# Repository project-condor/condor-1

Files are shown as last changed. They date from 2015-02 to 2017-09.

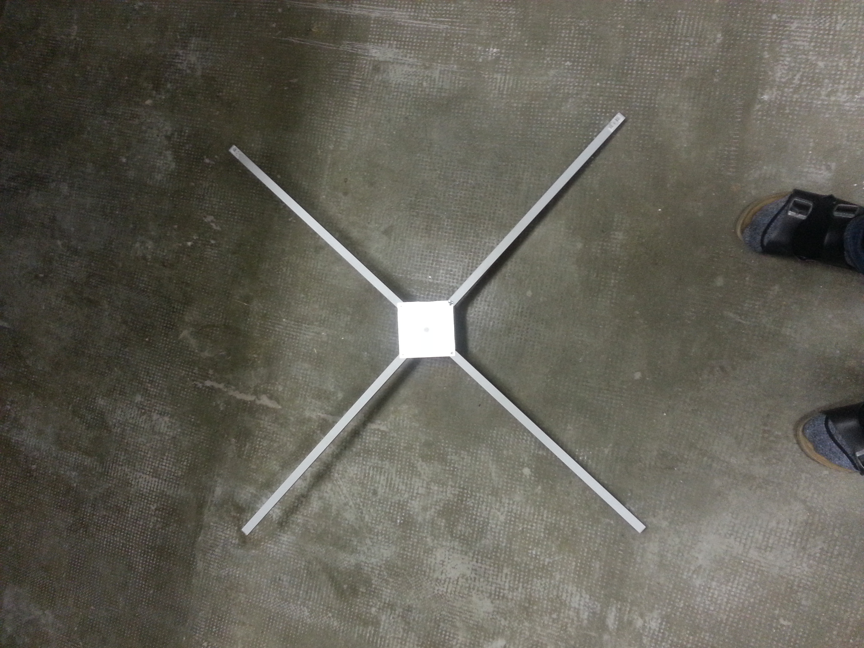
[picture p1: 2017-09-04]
prototype/pictures/frame-final.jpg

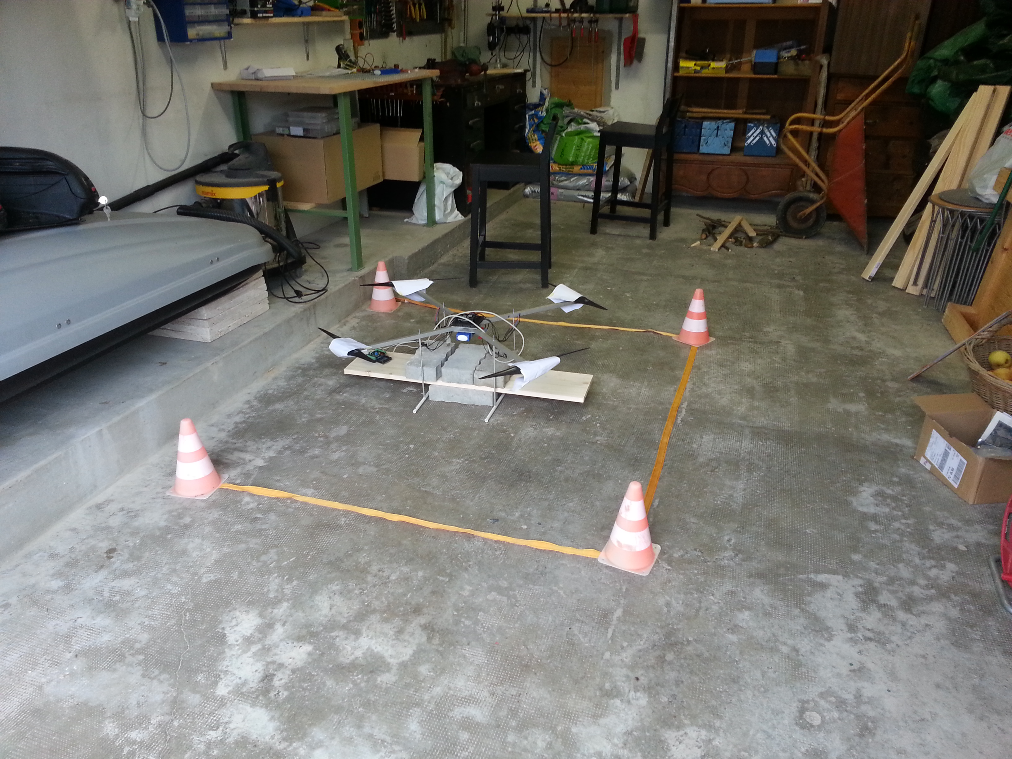
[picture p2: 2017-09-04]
prototype/pictures/condor1.jpg

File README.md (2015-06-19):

# Condor - 1

Project Condor regroups several smaller projects with the aim of creating a fully open source quadcopter.

This repository contains files related to the quadcopter model. Checkout the [functional diagram](functional.svg), and a [computer rendition](prototype/preview.png) of the prototype.

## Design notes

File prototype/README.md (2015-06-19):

# Condor - 1 - 1

This directory contains files related to the first prototype (the actual physical unit) of the condor project.

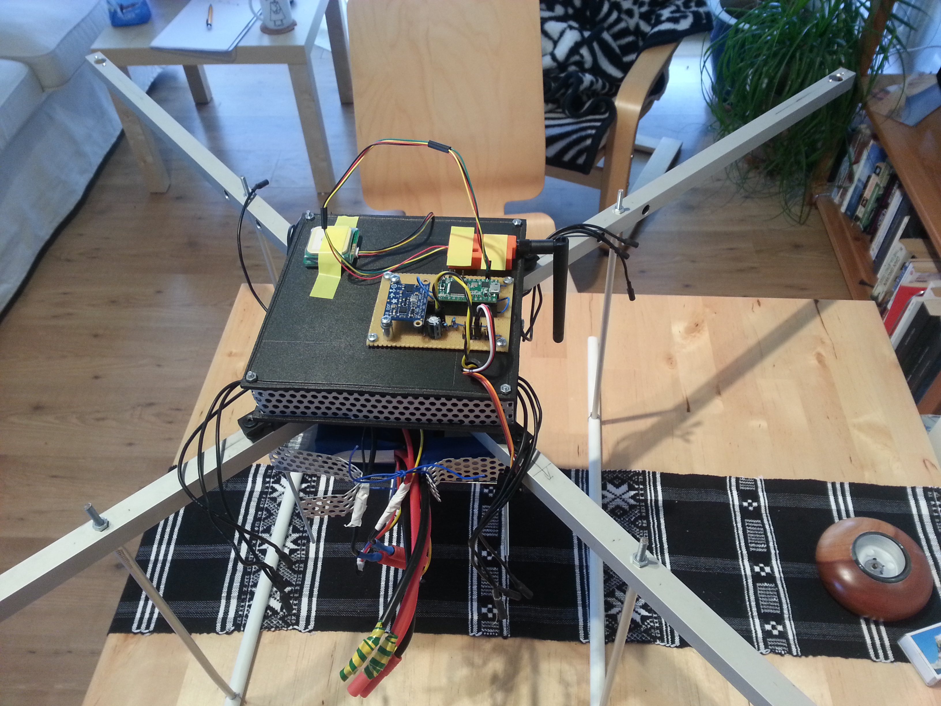
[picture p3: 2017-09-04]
prototype/pictures/closeup.jpg

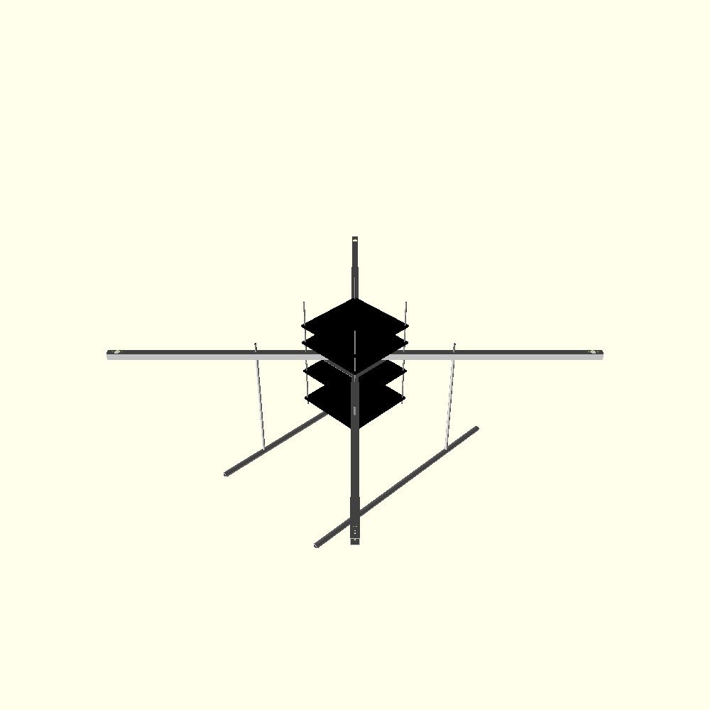
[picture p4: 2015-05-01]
prototype/preview.png

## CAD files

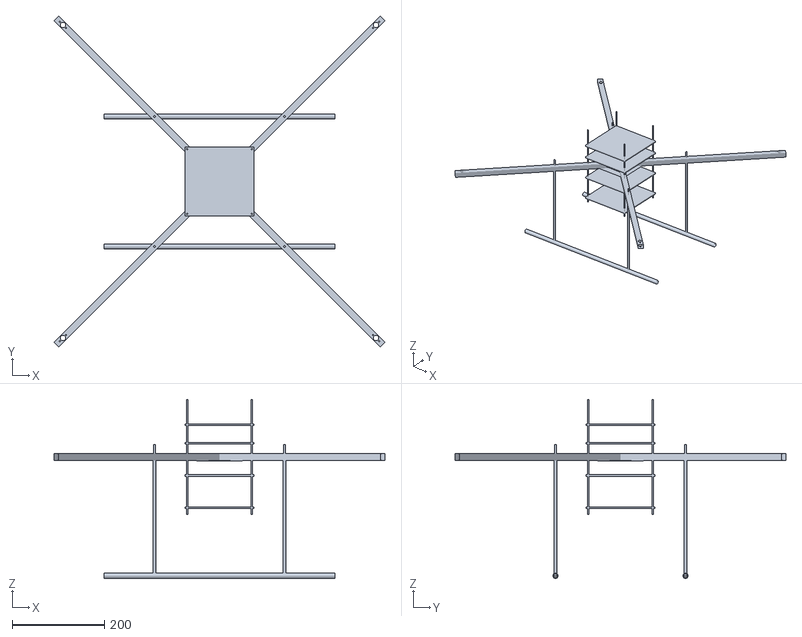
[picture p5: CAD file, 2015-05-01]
prototype/mainframe.stl
717.7 x 717.7 x 388.5

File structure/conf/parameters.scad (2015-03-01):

//rendering
epsilon=0.01;

//model
frame_length=1000;
frame_inner=19;
frame_outer=20;

support_width=100;
support_height=0.2;
support_inner=90;
support_diameter=3;

rack_width=150;
rack_inner=140;
rack_diameter=3;

stand_height=200;
stand_width=200;
stand_diameter=5;
stand_head_height=20;
stand_head_diameter=4;

foot_outer=12;
foot_inner=10;
foot_length=500;

motor_hole_distance=450;
motor_hole_diameter=12;
motor_mount_distance=19;
motor_mount_diameter=3;

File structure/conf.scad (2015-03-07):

//rendering
epsilon=0.1;

//model
frame_length=1000;
frame_inner=13.5;
frame_outer=15;

support_width=100;
support_height=0.75;
support_inner=90;
support_diameter=3;

rack_width=150;
rack_inner=140;
rack_diameter=3;
rack_height=250;
rack_plate_height=4;

stand_height=250;
stand_width=282;
stand_diameter=6;
stand_head_height=35;
stand_head_diameter=4;

foot_outer=12;
foot_inner=8;
foot_length=500;

motor_hole_distance=480;
motor_hole_diameter=12;
motor_mount_distance=19;
motor_mount_diameter=3;

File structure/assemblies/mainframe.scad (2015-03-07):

include <../conf.scad>
use <../parts/crossbar.scad>
use <../parts/support_plate.scad>
use <../parts/stand.scad>
use <../parts/foot.scad>
use <../parts/rack_mount.scad>
use <../parts/rack_plate.scad>

$fn=10;

explode=0;

module main(explode=0) {
	translate([0,0,-explode])
	rotate([0,0,45])
	crossbar();

	translate([0,0,explode])
	rotate([180,0,-45])
	crossbar();
}

module support(explode=0) {
	translate([0,0,explode])
	translate([0,0,(frame_outer+support_height)/2])
	support_plate();

	translate([0,0,-explode])
	translate([0,0,-(frame_outer+support_height)/2])
	support_plate();
}

module stands(explode=0) {
	translate([0,0,-explode])
	for (i = [0:3]) {
		rotate([0,0,i*90])
		translate([stand_width/2,stand_width/2,-stand_height/2 - frame_outer/2])
		stand();
	}
}

module feet(explode=0) {
	translate([0,0,-explode]) {
		translate([0, stand_width/2, -stand_height - frame_outer/2])
		foot();
		translate([0, -stand_width/2, -stand_height - frame_outer/2])
		foot();
	}
}
module rack_mounts(explode=0) {
	translate([0,0,explode])
	for (i = [0:3]) {
		rotate([0,0,i*90])
		translate([rack_inner/2,rack_inner/2,0])
		rack_mount();
	}

}

main(explode);
support(explode*2);
stands(explode*3);
feet(explode*4);

rack_mounts(explode*10);
translate([0,0,30])
rack_plate();
translate([0,0,70])
rack_plate();
translate([0,0,-40])
rack_plate();
translate([0,0,-110])
rack_plate();

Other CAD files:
structure/parts/crossbar.scad
structure/parts/foot.scad
structure/parts/rack_mount.scad
structure/parts/rack_plate.scad
structure/parts/stand.scad
structure/parts/support_plate.scad

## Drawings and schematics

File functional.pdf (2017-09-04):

## GPS

## Ground Station

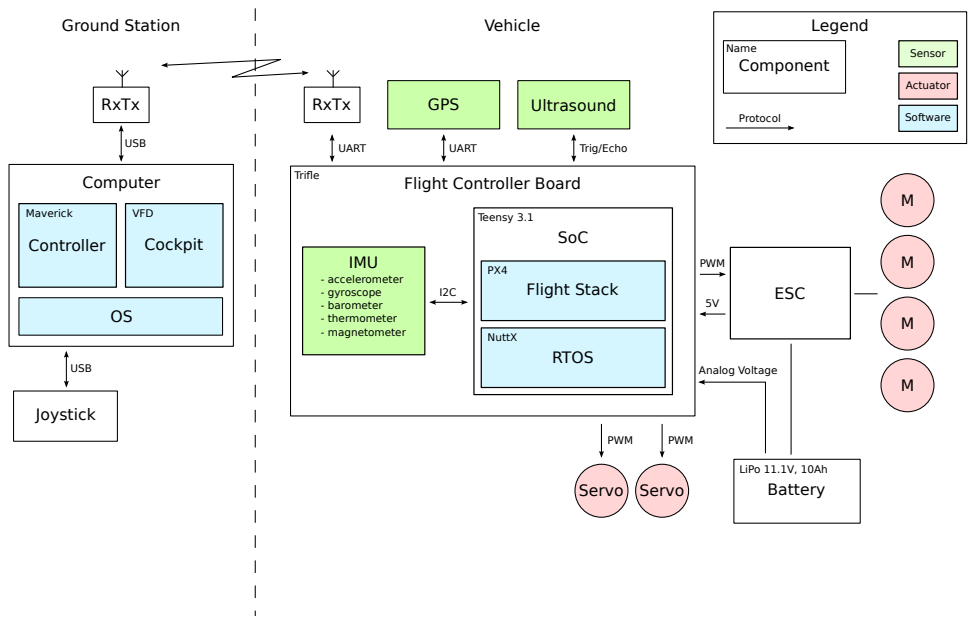
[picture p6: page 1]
SoC; RTOS; NuttX; Flight Stack; Teensy 3.1; IMU; Trifle; PWM; ESC; RxTx; Maverick; Joystick; Computer; - accelerometer - gyroscope - barometer - thermometer - magnetometer; Vehicle; VFD; Controller; Cockpit; USB; Ultrasound; UART; Trig/Echo; LiPo 11.1V, 10Ah Battery; Component; Name; Protocol; Software; Sensor; Analog Voltage; Actuator; Legend; Servo

Flight Controller Board

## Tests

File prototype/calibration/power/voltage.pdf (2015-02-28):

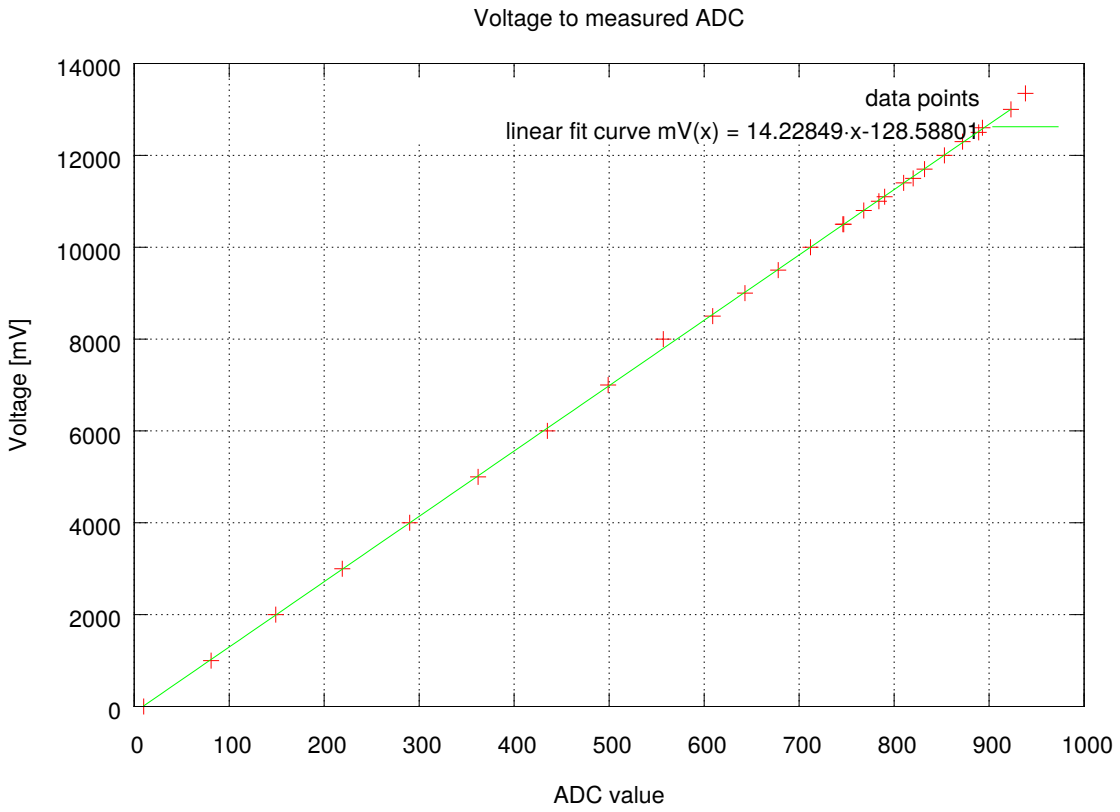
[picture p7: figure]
Voltage [mV]; ADC value; Voltage to measured ADC; data points

linear fit curve mV(x) = 14.22849·x-128.58801

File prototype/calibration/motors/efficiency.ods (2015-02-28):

Voltage[V] | Current [A] | Power [W] | Pull [g] | Efficiency [g/W]
11.1 | 6.4 | 71.04 | 500 | 7.0382882883
11.1 | 6.8 | 75.48 | 650 | 8.6115527292
11.1 | 8.3 | 92.13 | 740 | 8.0321285141
11.1 | 13 | 144.3 | 1020 | 7.0686070686
14.8 | 10.4 | 153.92 | 830 | 5.3924116424
14.8 | 11.1 | 164.28 | 1000 | 6.0871682493
14.8 | 13.1 | 193.88 | 1200 | 6.1893955024
14.8 | 21.2 | 313.76 | 1590 | 5.0675675676
18.5 | 15.3 | 283.05 | 1240 | 4.3808514397
18.5 | 16.1 | 297.85 | 1470 | 4.9353701528
18.5 | 18.7 | 345.95 | 1730 | 5.0007226478
18.5 | 29 | 536.5 | 1970 | 3.6719478099
22.2 | 21 | 466.2 | 1650 | 3.5392535393
22.2 | 21.8 | 483.96 | 1940 | 4.0085957517
22.2 | 23.9 | 530.58 | 2190 | 4.1275585209

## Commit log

2015-03-01 basic modeling
    [crossbar.scad, foot.scad, mainframe.scad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]
2015-03-07 use dimensions of prototype
    [conf.scad, crossbar.scad, foot.scad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]
2015-05-01 add prototype
    [efficiency.ods, mainframe.stl]
2015-06-19 change color of rack plates
    [rack_plate.scad]
